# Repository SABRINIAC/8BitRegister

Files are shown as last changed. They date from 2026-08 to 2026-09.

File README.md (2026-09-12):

# CPU Registers & Tristate Buffers for the SABRINIAC
This project creates the PCBs for my CPU registers and the tristate buffers to I/O with them.

It is for my '60s inspired computer im making base don the Intel 8080. At the time of writing this I have RAM + it's clock done and the ALU Modules done. After I get the registers + buffers I'll only have to make a motherboard and an opcode decoder/microcode.

The SABRINIAC is my '60s inspired, transistor based,, Intel 8008 Architecture computer. Every part of it from the instruction decoder to the alu will be built using purely transistors.

You can check out the other repos for the SABRINAIC's parts [here](https://github.com/orgs/SABRINIAC/repositories) or you can check out the ALU's repo which explains in more detail what the SABRINIAC is [here](https://github.com/SABRINIAC/ALU-Components)





How to assemble? Just solder on all of the 2N2222 Transistors (or other NPN transitors) and 0603 1kohm resistors

BOM:

| Part Name | Count | Link | Cost |
|---|---|---|---|
| Register PCBs | 18 | From JLCPCB | $10.20 |
| Tri-State Buffer PCBs | 26 | From JLCPCB | $13.30 |
| 2N2222 NPN Transistors | 1406 | https://www.aliexpress.us/item/3256806831821651.html | $15 |
| 0603 SMD 1kohm Resistors | 2684 | https://www.aliexpress.us/item/3256805937811409.html | $12.56 |
| Pin headers | Any combination of 1xN Right Angle Male Pin Headers to make up 1x854 | I already have them but something like this: https://www.aliexpress.us/item/3256803319359683.html | $3 |
| Total | - | - | ~$70 |

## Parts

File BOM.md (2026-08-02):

BOM Per Register
- 1x PCB
- 1x 1x20 Right Angle Male Pin Header
- 100x 1k 0603 SMD Resistors
- 42x 2n2222 NPN Transistors

BOM Per Tri-state Buffer
- 1x PCB
- 1x 1x19 Right Angle Male Pin Header
- 34x 1k 0603 SMD Resistors
- 25x 2n2222 NPN Transistors

For the SABRINIAC I need:
- 18x registers (A, F, B, C, D, E, H, L, W, Z, SP1, SP2, PC1, PC2, M, RAM1, RAM2, TEMP)
- 26x Tri-state Buffers (1 for each register, 1 for each ALU component)

This equates to this BOM:
- 18x Register PCBs
- 26x Tri-state buffer PCBs
- 1406x 2n2222 NPN Transistors
- 2684x 1k 0603 SMD Resistors
- Any combination of 1xN Right Angle Male Pin Headers to make up 1x854

Cost:
- PCBs + Shipping = $38.69
- 1700x 2n2222 NPN Transistors from Aliepxress + Free Shipping = $26.69 (https://www.aliexpress.us/item/3256806831821651.html)
- 1k 0603 SMD Resistors, $0 I already have a bunch from this order (https://www.aliexpress.us/item/3256805937811409.html) and ones like it
- Right angle male pin headers I have already

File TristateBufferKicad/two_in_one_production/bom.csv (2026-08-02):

Designator | Footprint | Quantity | Value | LCSC Part #
J1_2, J1 | PinHeader_1x19_P2.54mm_Horizontal | 2 | Conn_01x19_Pin
Q1_2, Q1, Q10_2, Q10, Q11_2, Q11, Q12_2, Q12, Q13_2, Q13, Q14_2, Q14, Q15_2, Q15, Q16_2, Q16, Q17_2, Q17, Q18_2, Q18, Q19_2, Q19, Q2_2, Q2, Q20_2, Q20, Q21_2, Q21, Q22_2, Q22, Q23_2, Q23, Q24_2, Q24, Q25_2, Q25, Q3_2, Q3, Q4_2, Q4, Q5_2, Q5, Q6_2, Q6, Q7_2, Q7, Q8_2, Q8, Q9_2, Q9 | TO-92 | 50 | NPN
R1_2, R1, R10_2, R10, R11_2, R11, R12_2, R12, R13_2, R13, R14_2, R14, R15_2, R15, R16_2, R16, R17_2, R17, R18_2, R18, R19_2, R19, R2_2, R2, R20_2, R20, R21_2, R21, R22_2, R22, R23_2, R23, R24_2, R24, R25_2, R25, R26_2, R26, R27_2, R27, R28_2, R28, R29_2, R29, R3_2, R3, R30_2, R30, R31_2, R31, R32_2, R32, R33_2, R33, R34_2, R34, R4_2, R4, R5_2, R5, R6_2, R6, R7_2, R7, R8_2, R8, R9_2, R9 | 0603 | 68 | 1k

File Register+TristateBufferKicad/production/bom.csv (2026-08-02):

Designator | Footprint | Quantity | Value | LCSC Part #
J1 | PinHeader_1x20_P2.54mm_Horizontal | 1 | Conn_01x20_Pin
J2 | PinHeader_1x19_P2.54mm_Horizontal | 1 | Conn_01x19_Pin
Q1, Q10, Q11, Q12, Q13, Q14, Q15, Q16, Q17, Q18, Q19, Q2, Q20, Q21, Q22, Q23, Q24, Q25, Q26, Q27, Q28, Q29, Q3, Q30, Q31, Q32, Q33, Q34, Q35, Q36, Q37, Q38, Q39, Q4, Q40, Q41, Q42, Q43, Q44, Q45, Q46, Q47, Q48, Q49, Q5, Q50, Q51, Q52, Q53, Q54, Q55, Q56, Q57, Q58, Q59, Q6, Q60, Q61, Q62, Q63, Q64, Q65, Q66, Q67, Q7, Q8, Q9 | TO-92 | 67 | NPN
R1, R10, R100, R101, R102, R103, R104, R105, R106, R107, R108, R109, R11, R110, R111, R112, R113, R114, R115, R116, R117, R118, R119, R12, R120, R121, R122, R123, R124, R125, R126, R127, R128, R129, R13, R130, R131, R132, R133, R134, R14, R15, R16, R17, R18, R19, R2, R20, R21, R22, R23, R24, R25, R26, R27, R28, R29, R3, R30, R31, R32, R33, R34, R35, R36, R37, R38, R39, R4, R40, R41, R42, R43, R44, R45, R46, R47, R48, R49, R5, R50, R51, R52, R53, R54, R55, R56, R57, R58, R59, R6, R60, R61, R62, R63, R64, R65, R66, R67, R68, R69, R7, R70, R71, R72, R73, R74, R75, R76, R77, R78, R79, R8, R80, R81, R82, R83, R84, R85, R86, R87, R88, R89, R9, R90, R91, R92, R93, R94, R95, R96, R97, R98, R99 | 0603 | 134 | 1k

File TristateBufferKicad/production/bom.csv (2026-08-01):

Designator | Footprint | Quantity | Value | LCSC Part #
J1 | PinHeader_1x19_P2.54mm_Horizontal | 1 | Conn_01x19_Pin
Q1, Q10, Q11, Q12, Q13, Q14, Q15, Q16, Q17, Q18, Q19, Q2, Q20, Q21, Q22, Q23, Q24, Q25, Q3, Q4, Q5, Q6, Q7, Q8, Q9 | TO-92 | 25 | NPN
R1, R10, R11, R12, R13, R14, R15, R16, R17, R18, R19, R2, R20, R21, R22, R23, R24, R25, R26, R27, R28, R29, R3, R30, R31, R32, R33, R34, R4, R5, R6, R7, R8, R9 | 0603 | 34 | 1k

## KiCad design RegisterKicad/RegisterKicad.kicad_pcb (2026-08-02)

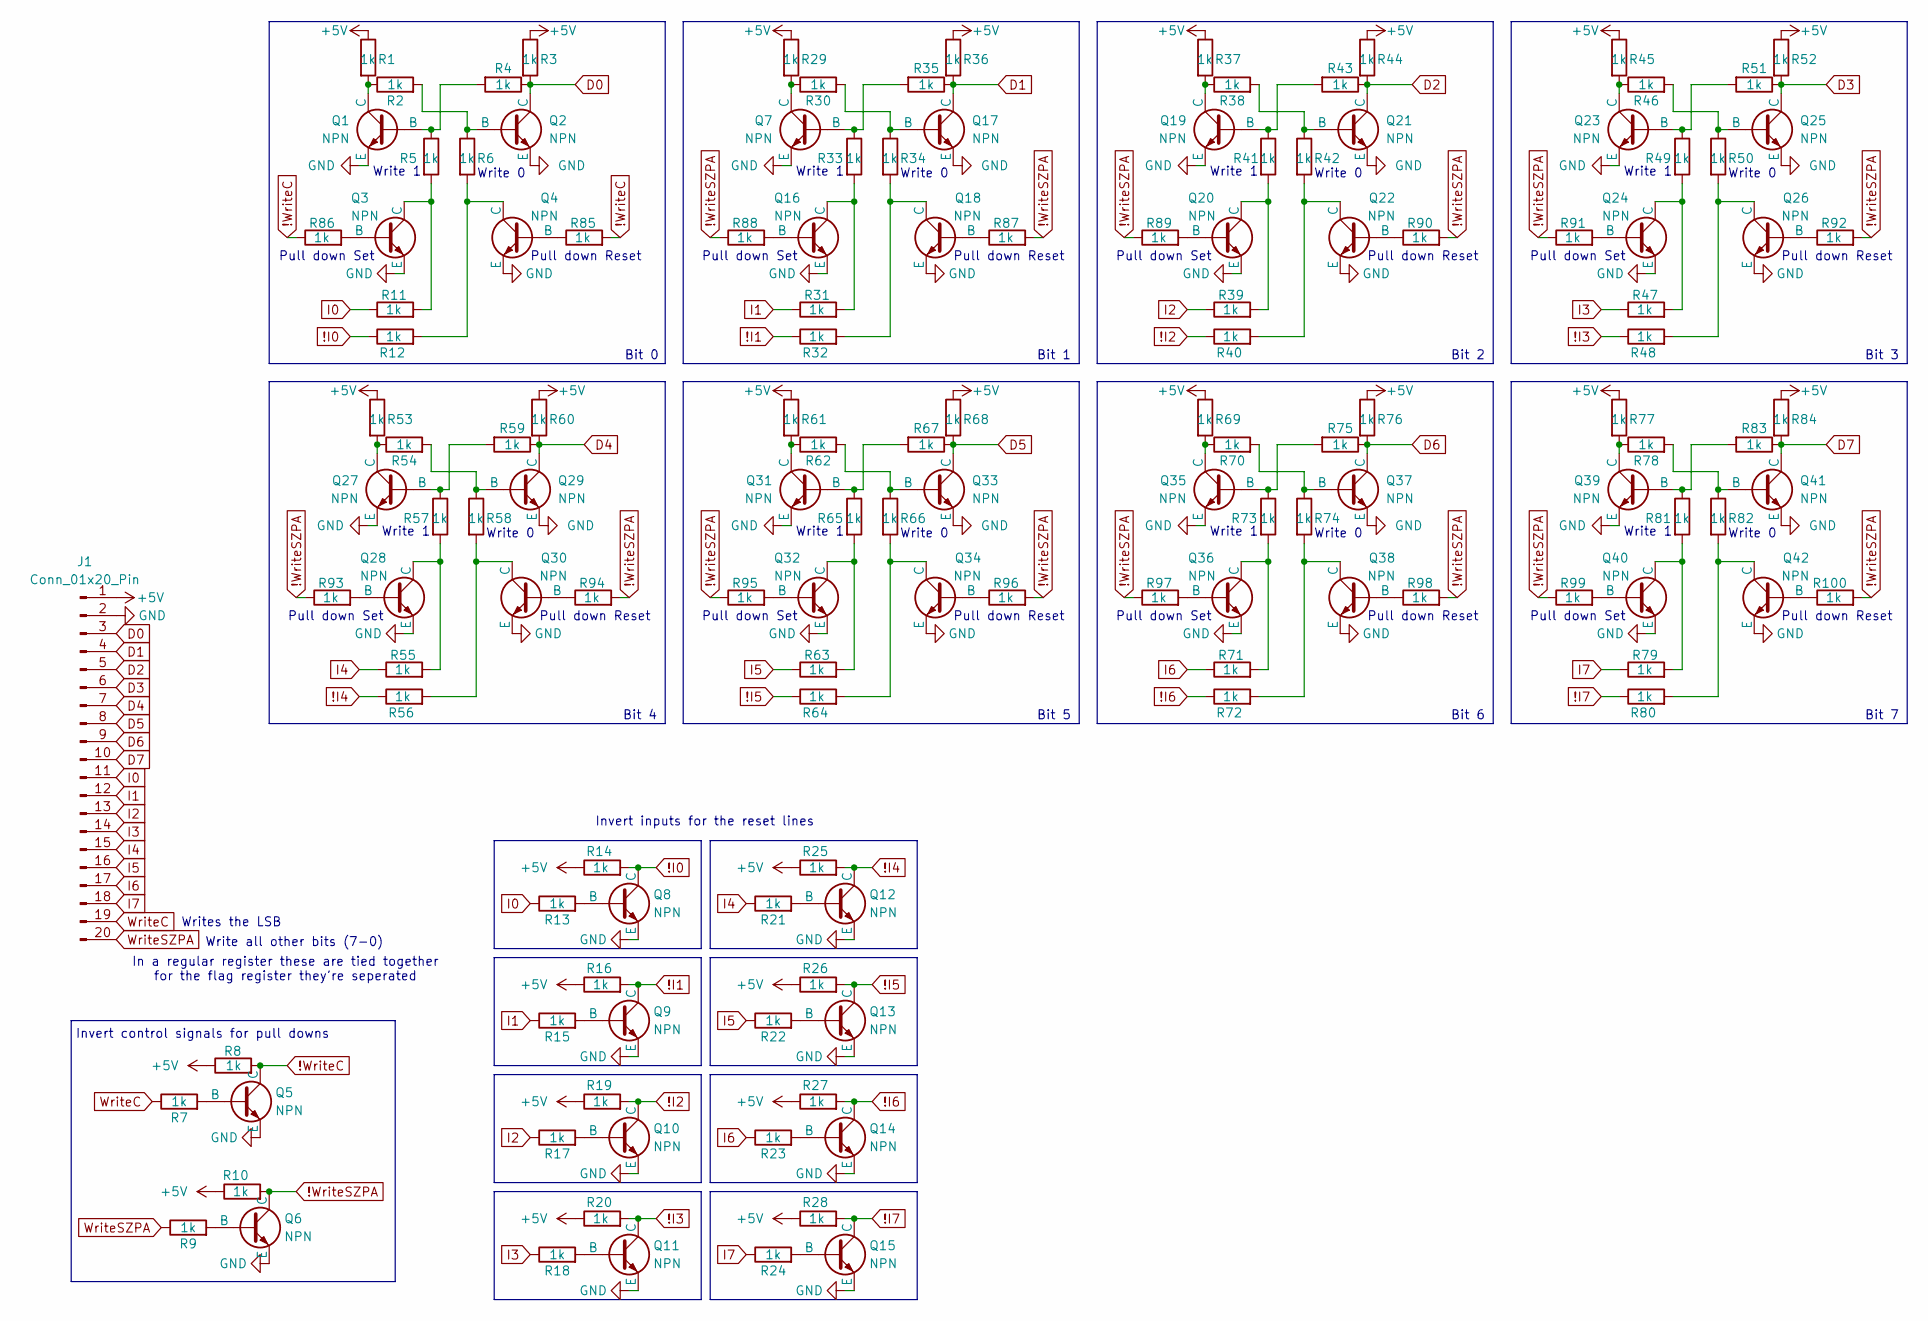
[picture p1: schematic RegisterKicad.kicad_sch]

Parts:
J1: Conn_01x20_Pin; PinHeader_1x20_P2.54mm_Horizontal
Q1, Q2, Q3, Q4, Q5, Q6, Q7, Q8, Q9, Q10, Q11, Q12, Q13, Q14, Q15, Q16, Q17, Q18, Q19, Q20, Q21, Q22, Q23, Q24, Q25, Q26, Q27, Q28, Q29, Q30, Q31, Q32, Q33, Q34, Q35, Q36, Q37, Q38, Q39, Q40, Q41, Q42: NPN; TO-92
R1, R2, R3, R4, R5, R6, R7, R8, R9, R10, R11, R12, R13, R14, R15, R16, R17, R18, R19, R20, R21, R22, R23, R24, R25, R26, R27, R28, R29, R30, R31, R32, R33, R34, R35, R36, R37, R38, R39, R40, R41, R42, R43, R44, R45, R46, R47, R48, R49, R50, R51, R52, R53, R54, R55, R56, R57, R58, R59, R60, R61, R62, R63, R64, R65, R66, R67, R68, R69, R70, R71, R72, R73, R74, R75, R76, R77, R78, R79, R80, R81, R82, R83, R84, R85, R86, R87, R88, R89, R90, R91, R92, R93, R94, R95, R96, R97, R98, R99, R100: 1k; R_0603_1608Metric_Pad0.98x0.95mm_HandSolder

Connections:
!I0: Q8.1 (C), R12.1, R14.2
!I1: Q9.1 (C), R16.2, R32.1
!I2: Q10.1 (C), R19.2, R40.1
!I3: Q11.1 (C), R20.2, R48.1
!I4: Q12.1 (C), R25.2, R56.1
!I5: Q13.1 (C), R26.2, R64.1
!I6: Q14.1 (C), R27.2, R72.1
!I7: Q15.1 (C), R28.2, R80.1
!WriteC: Q5.1 (C), R8.2, R85.2, R86.1
!WriteSZPA: Q6.1 (C), R10.2, R87.2, R88.1, R89.1, R90.2, R91.1, R92.2, R93.1, R94.2, R95.1, R96.2, R97.1, R98.2, R99.1, R100.2
+5V: J1.1, R1.1, R3.1, R8.1, R10.1, R14.1, R16.1, R19.1, R20.1, R25.1, R26.1, R27.1, R28.1, R29.1, R36.1, R37.1, R44.1, R45.1, R52.1, R53.1, R60.1, R61.1, R68.1, R69.1, R76.1, R77.1, R84.1
D0: J1.3, Q2.1 (C), R3.2, R4.1
D1: J1.4, Q17.1 (C), R35.1, R36.2
D2: J1.5, Q21.1 (C), R43.1, R44.2
D3: J1.6, Q25.1 (C), R51.1, R52.2
D4: J1.7, Q29.1 (C), R59.1, R60.2
D5: J1.8, Q33.1 (C), R67.1, R68.2
D6: J1.9, Q37.1 (C), R75.1, R76.2
D7: J1.10, Q41.1 (C), R83.1, R84.2
GND: J1.2, Q1.3 (E), Q2.3 (E), Q3.3 (E), Q4.3 (E), Q5.3 (E), Q6.3 (E), Q7.3 (E), Q8.3 (E), Q9.3 (E), Q10.3 (E), Q11.3 (E), Q12.3 (E), Q13.3 (E), Q14.3 (E), Q15.3 (E), Q16.3 (E), Q17.3 (E), Q18.3 (E), Q19.3 (E), Q20.3 (E), Q21.3 (E), Q22.3 (E), Q23.3 (E), Q24.3 (E), Q25.3 (E), Q26.3 (E), Q27.3 (E), Q28.3 (E), Q29.3 (E), Q30.3 (E), Q31.3 (E), Q32.3 (E), Q33.3 (E), Q34.3 (E), Q35.3 (E), Q36.3 (E), Q37.3 (E), Q38.3 (E), Q39.3 (E), Q40.3 (E), Q41.3 (E), Q42.3 (E)
I0: J1.11, R11.1, R13.1
I1: J1.12, R15.1, R31.1
I2: J1.13, R17.1, R39.1
I3: J1.14, R18.1, R47.1
I4: J1.15, R21.1, R55.1
I5: J1.16, R22.1, R63.1
I6: J1.17, R23.1, R71.1
I7: J1.18, R24.1, R79.1
unnamed: Q1.2 (B), R4.2, R5.1
unnamed: Q1.1 (C), R1.2, R2.1
unnamed: Q2.2 (B), R2.2, R6.1
unnamed: Q3.2 (B), R86.2
unnamed: Q3.1 (C), R5.2, R11.2
unnamed: Q4.2 (B), R85.1
unnamed: Q4.1 (C), R6.2, R12.2
unnamed: Q5.2 (B), R7.2
unnamed: Q6.2 (B), R9.2
unnamed: Q7.2 (B), R33.1, R35.2
unnamed: Q7.1 (C), R29.2, R30.1
unnamed: Q8.2 (B), R13.2
unnamed: Q9.2 (B), R15.2
unnamed: Q10.2 (B), R17.2
unnamed: Q11.2 (B), R18.2
unnamed: Q12.2 (B), R21.2
unnamed: Q13.2 (B), R22.2
unnamed: Q14.2 (B), R23.2
unnamed: Q15.2 (B), R24.2
unnamed: Q16.2 (B), R88.2
unnamed: Q16.1 (C), R31.2, R33.2
unnamed: Q17.2 (B), R30.2, R34.1
unnamed: Q18.2 (B), R87.1
unnamed: Q18.1 (C), R32.2, R34.2
unnamed: Q19.2 (B), R41.1, R43.2
unnamed: Q19.1 (C), R37.2, R38.1
unnamed: Q20.2 (B), R89.2
unnamed: Q20.1 (C), R39.2, R41.2
unnamed: Q21.2 (B), R38.2, R42.1
unnamed: Q22.2 (B), R90.1
unnamed: Q22.1 (C), R40.2, R42.2
unnamed: Q23.2 (B), R49.1, R51.2
unnamed: Q23.1 (C), R45.2, R46.1
unnamed: Q24.2 (B), R91.2
unnamed: Q24.1 (C), R47.2, R49.2
unnamed: Q25.2 (B), R46.2, R50.1
unnamed: Q26.2 (B), R92.1
unnamed: Q26.1 (C), R48.2, R50.2
unnamed: Q27.2 (B), R57.1, R59.2
unnamed: Q27.1 (C), R53.2, R54.1
unnamed: Q28.2 (B), R93.2
unnamed: Q28.1 (C), R55.2, R57.2
unnamed: Q29.2 (B), R54.2, R58.1
unnamed: Q30.2 (B), R94.1
unnamed: Q30.1 (C), R56.2, R58.2
unnamed: Q31.2 (B), R65.1, R67.2
unnamed: Q31.1 (C), R61.2, R62.1
unnamed: Q32.2 (B), R95.2
unnamed: Q32.1 (C), R63.2, R65.2
unnamed: Q33.2 (B), R62.2, R66.1
unnamed: Q34.2 (B), R96.1
unnamed: Q34.1 (C), R64.2, R66.2
unnamed: Q35.2 (B), R73.1, R75.2
unnamed: Q35.1 (C), R69.2, R70.1
unnamed: Q36.2 (B), R97.2
unnamed: Q36.1 (C), R71.2, R73.2
unnamed: Q37.2 (B), R70.2, R74.1
unnamed: Q38.2 (B), R98.1
unnamed: Q38.1 (C), R72.2, R74.2
unnamed: Q39.2 (B), R81.1, R83.2
unnamed: Q39.1 (C), R77.2, R78.1
unnamed: Q40.2 (B), R99.2
unnamed: Q40.1 (C), R79.2, R81.2
unnamed: Q41.2 (B), R78.2, R82.1
unnamed: Q42.2 (B), R100.1
unnamed: Q42.1 (C), R80.2, R82.2
WriteC: J1.19, R7.1
WriteSZPA: J1.20, R9.1

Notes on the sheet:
Bit 2
In a regular register these are tied together for the flag register they're seperated
Pull down Reset
Write 1
Bit 1
Pull down Set
Invert control signals for pull downs
Write 0
Invert inputs for the reset lines
Bit 6
Bit 3
Bit 5
Bit 7
Bit 4
Bit 0
Write all other bits (7-0)
Writes the LSB

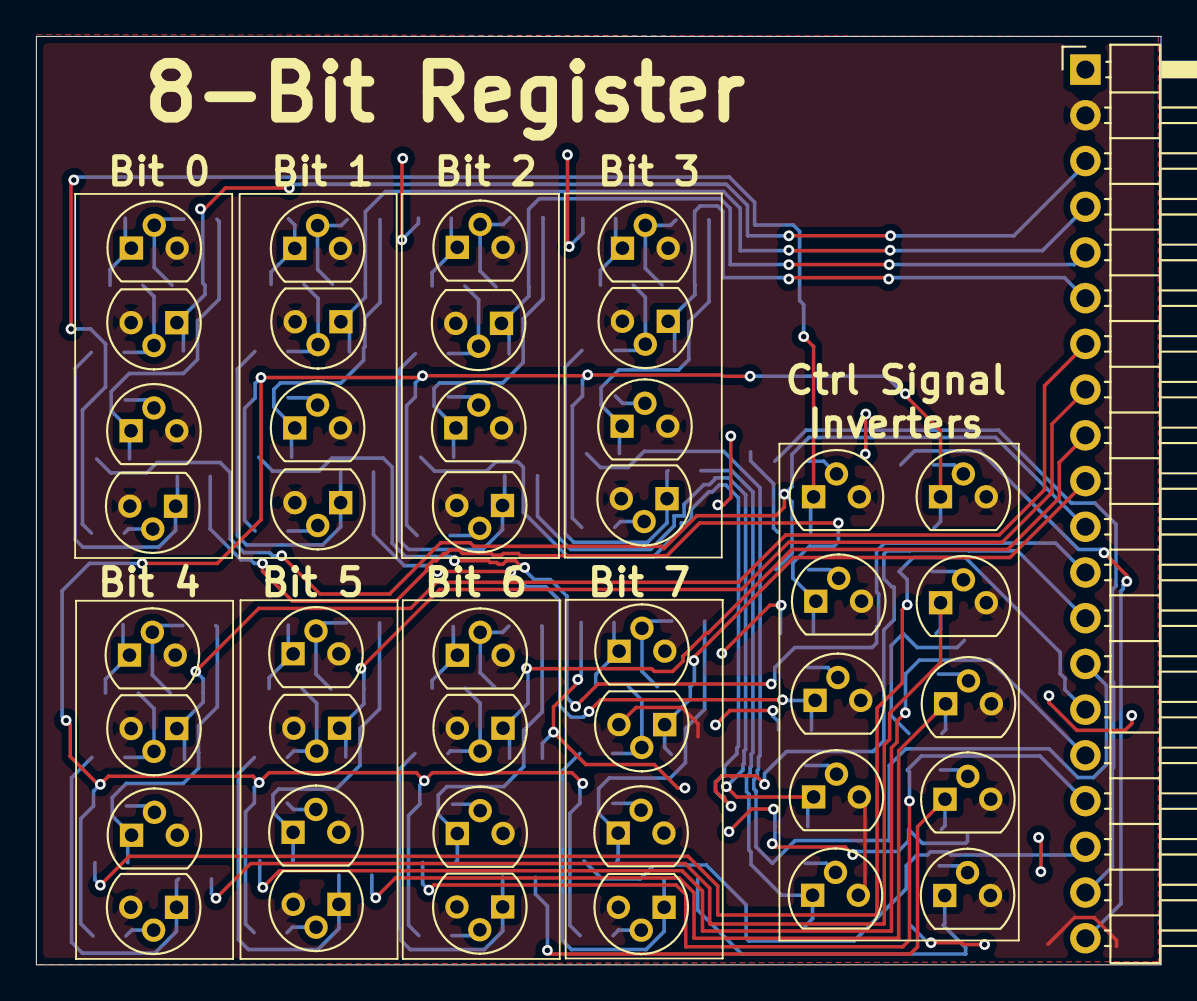
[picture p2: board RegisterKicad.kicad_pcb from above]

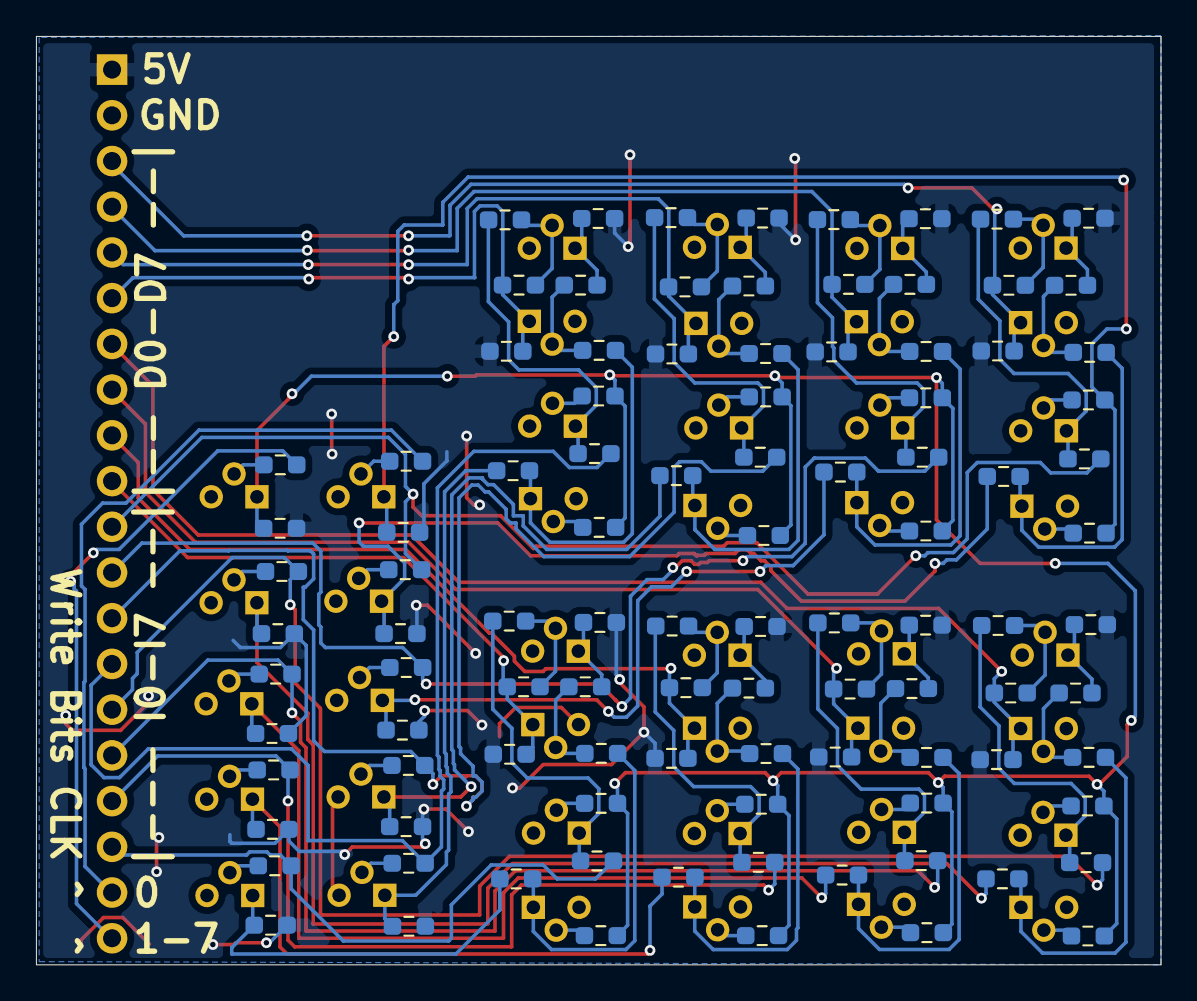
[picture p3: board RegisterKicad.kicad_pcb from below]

Board: 2 copper layers, 62.5 x 51.6 mm, 143 parts (100 on the bottom side), 96 nets.

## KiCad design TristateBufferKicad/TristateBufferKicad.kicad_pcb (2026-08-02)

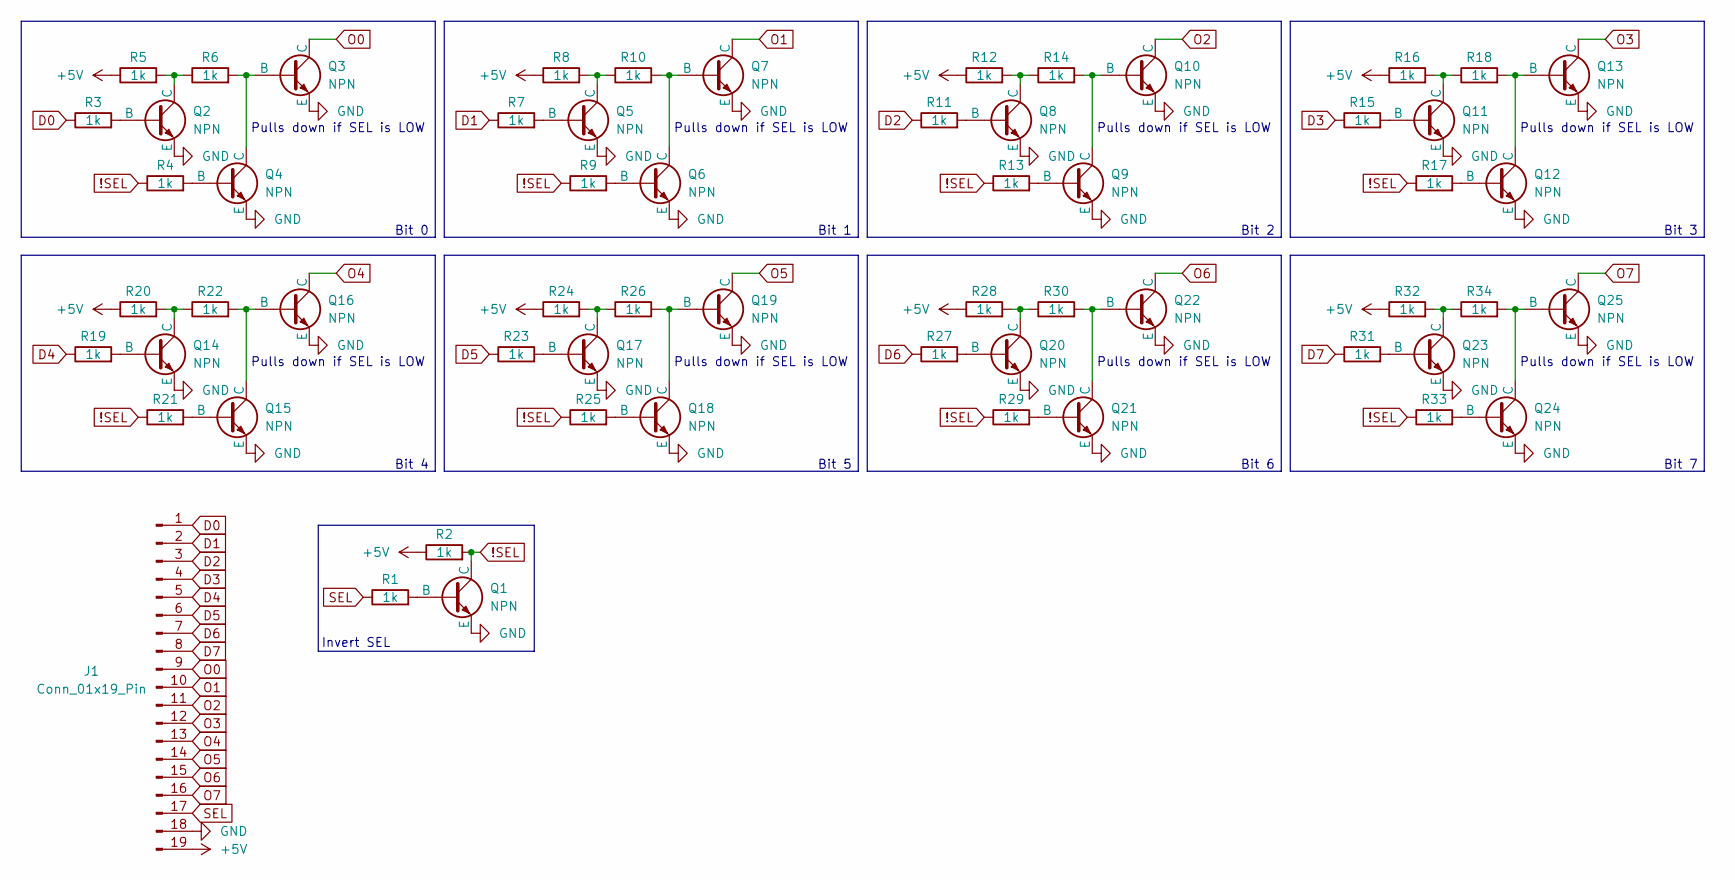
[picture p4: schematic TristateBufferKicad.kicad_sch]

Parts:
J1: Conn_01x19_Pin; PinHeader_1x19_P2.54mm_Horizontal
Q1, Q2, Q3, Q4, Q5, Q6, Q7, Q8, Q9, Q10, Q11, Q12, Q13, Q14, Q15, Q16, Q17, Q18, Q19, Q20, Q21, Q22, Q23, Q24, Q25: NPN; TO-92
R1, R2, R3, R4, R5, R6, R7, R8, R9, R10, R11, R12, R13, R14, R15, R16, R17, R18, R19, R20, R21, R22, R23, R24, R25, R26, R27, R28, R29, R30, R31, R32, R33, R34: 1k; R_0603_1608Metric_Pad0.98x0.95mm_HandSolder

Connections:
!SEL: Q1.1 (C), R2.2, R4.1, R9.1, R13.1, R17.1, R21.1, R25.1, R29.1, R33.1
+5V: J1.19, R2.1, R5.1, R8.1, R12.1, R16.1, R20.1, R24.1, R28.1, R32.1
D0: J1.1, R3.1
D1: J1.2, R7.1
D2: J1.3, R11.1
D3: J1.4, R15.1
D4: J1.5, R19.1
D5: J1.6, R23.1
D6: J1.7, R27.1
D7: J1.8, R31.1
GND: J1.18, Q1.3 (E), Q2.3 (E), Q3.3 (E), Q4.3 (E), Q5.3 (E), Q6.3 (E), Q7.3 (E), Q8.3 (E), Q9.3 (E), Q10.3 (E), Q11.3 (E), Q12.3 (E), Q13.3 (E), Q14.3 (E), Q15.3 (E), Q16.3 (E), Q17.3 (E), Q18.3 (E), Q19.3 (E), Q20.3 (E), Q21.3 (E), Q22.3 (E), Q23.3 (E), Q24.3 (E), Q25.3 (E)
unnamed: Q1.2 (B), R1.2
unnamed: Q2.2 (B), R3.2
unnamed: Q2.1 (C), R5.2, R6.1
unnamed: Q3.2 (B), Q4.1 (C), R6.2
unnamed: Q4.2 (B), R4.2
unnamed: Q5.2 (B), R7.2
unnamed: Q5.1 (C), R8.2, R10.1
unnamed: Q6.2 (B), R9.2
unnamed: Q6.1 (C), Q7.2 (B), R10.2
unnamed: Q8.2 (B), R11.2
unnamed: Q8.1 (C), R12.2, R14.1
unnamed: Q9.2 (B), R13.2
unnamed: Q9.1 (C), Q10.2 (B), R14.2
unnamed: Q11.2 (B), R15.2
unnamed: Q11.1 (C), R16.2, R18.1
unnamed: Q12.2 (B), R17.2
unnamed: Q12.1 (C), Q13.2 (B), R18.2
unnamed: Q14.2 (B), R19.2
unnamed: Q14.1 (C), R20.2, R22.1
unnamed: Q15.2 (B), R21.2
unnamed: Q15.1 (C), Q16.2 (B), R22.2
unnamed: Q17.2 (B), R23.2
unnamed: Q17.1 (C), R24.2, R26.1
unnamed: Q18.2 (B), R25.2
unnamed: Q18.1 (C), Q19.2 (B), R26.2
unnamed: Q20.2 (B), R27.2
unnamed: Q20.1 (C), R28.2, R30.1
unnamed: Q21.2 (B), R29.2
unnamed: Q21.1 (C), Q22.2 (B), R30.2
unnamed: Q23.2 (B), R31.2
unnamed: Q23.1 (C), R32.2, R34.1
unnamed: Q24.2 (B), R33.2
unnamed: Q24.1 (C), Q25.2 (B), R34.2
O0: J1.9, Q3.1 (C)
O1: J1.10, Q7.1 (C)
O2: J1.11, Q10.1 (C)
O3: J1.12, Q13.1 (C)
O4: J1.13, Q16.1 (C)
O5: J1.14, Q19.1 (C)
O6: J1.15, Q22.1 (C)
O7: J1.16, Q25.1 (C)
SEL: J1.17, R1.1

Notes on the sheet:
Bit 2
Pulls down if SEL is LOW
Bit 1
Invert SEL
Bit 0
Bit 5
Bit 3
Bit 6
Bit 7
Bit 4

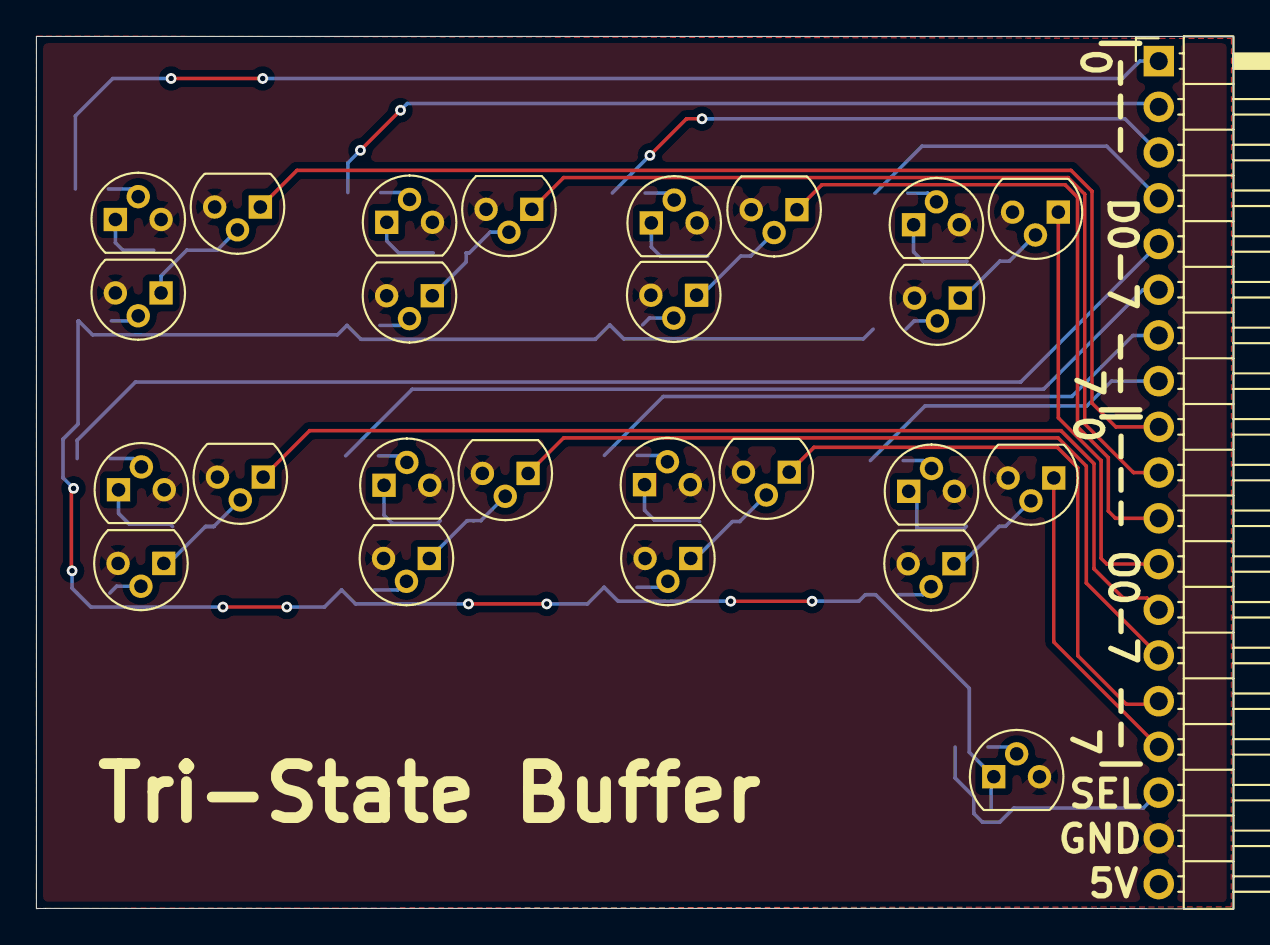
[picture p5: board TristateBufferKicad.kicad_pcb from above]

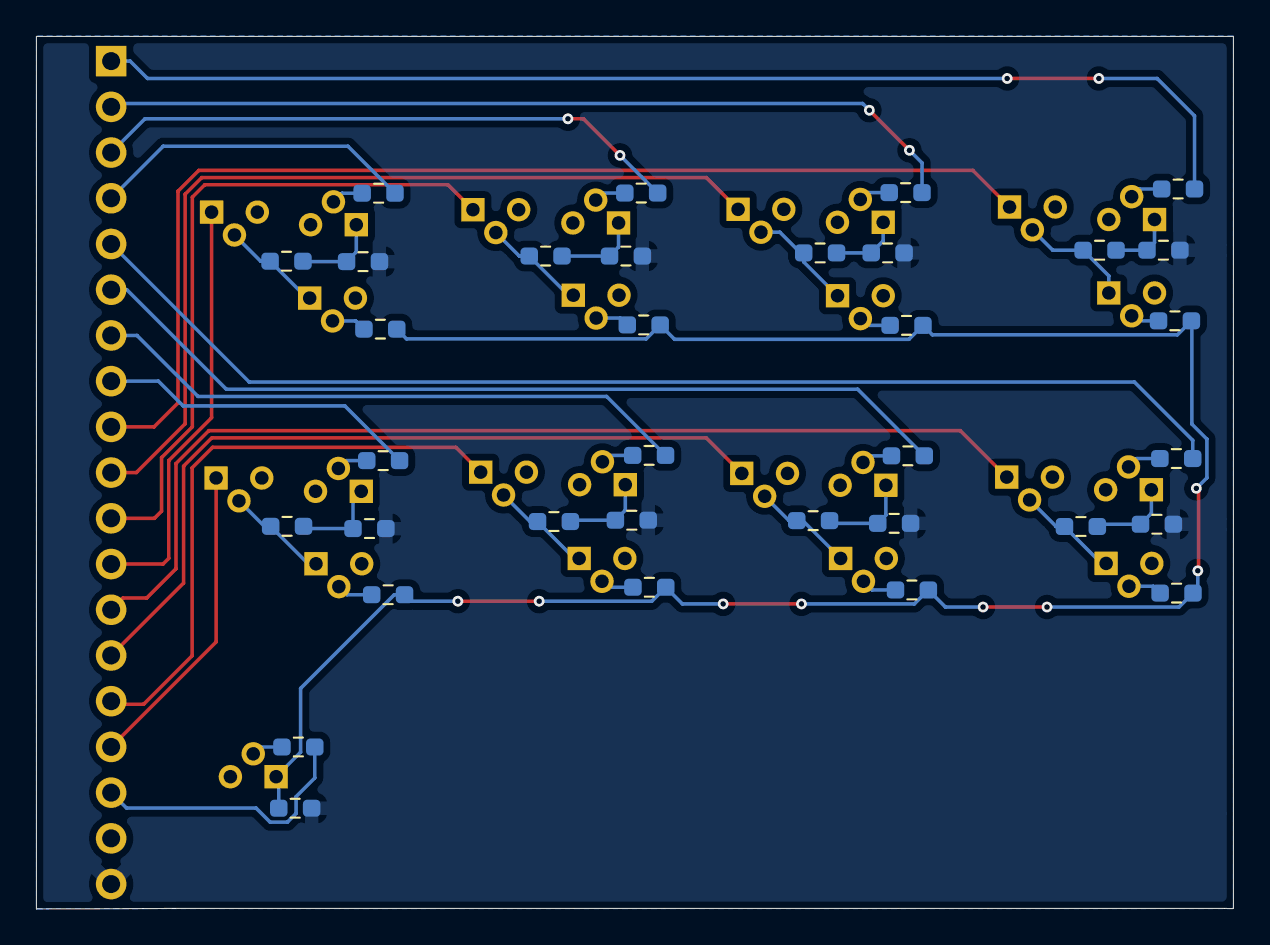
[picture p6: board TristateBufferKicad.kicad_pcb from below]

Board: 2 copper layers, 66.5 x 48.5 mm, 60 parts (34 on the bottom side), 53 nets.

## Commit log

2026-07-30 feat; removed unnecessary 16 bit register
    [16BitRegister_KicadPCB.kicad_pcb, 16BitRegister_KicadPCB.kicad_sch]
2026-08-01 feat: register done, need to do tri-state buffers next
    [RegisterKicad.kicad_pcb, RegisterKicad.kicad_sch, bom.csv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]
2026-08-01 closed kicad
2026-08-01 feat: schematic and routed tri-state buffer pcb, also added "8-Bit Register" text to register pcb
    [RegisterKicad.kicad_pcb, TristateBufferKicad.kicad_pcb, TristateBufferKicad.kicad_sch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]
2026-08-02 feat: made a combined tristate buffer + register pcb
    [Register+TristateBufferKicad.kicad_pcb, Register+TristateBufferKicad.kicad_sch, bom.csv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]
2026-08-02 feat: prod files for panelized tri-state buffer pcb. also bom update slightly
    [RegisterKicad.kicad_pcb, TristateBufferKicad.kicad_pcb, bom.csv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]
2026-09-10 feat: bom links in readme
